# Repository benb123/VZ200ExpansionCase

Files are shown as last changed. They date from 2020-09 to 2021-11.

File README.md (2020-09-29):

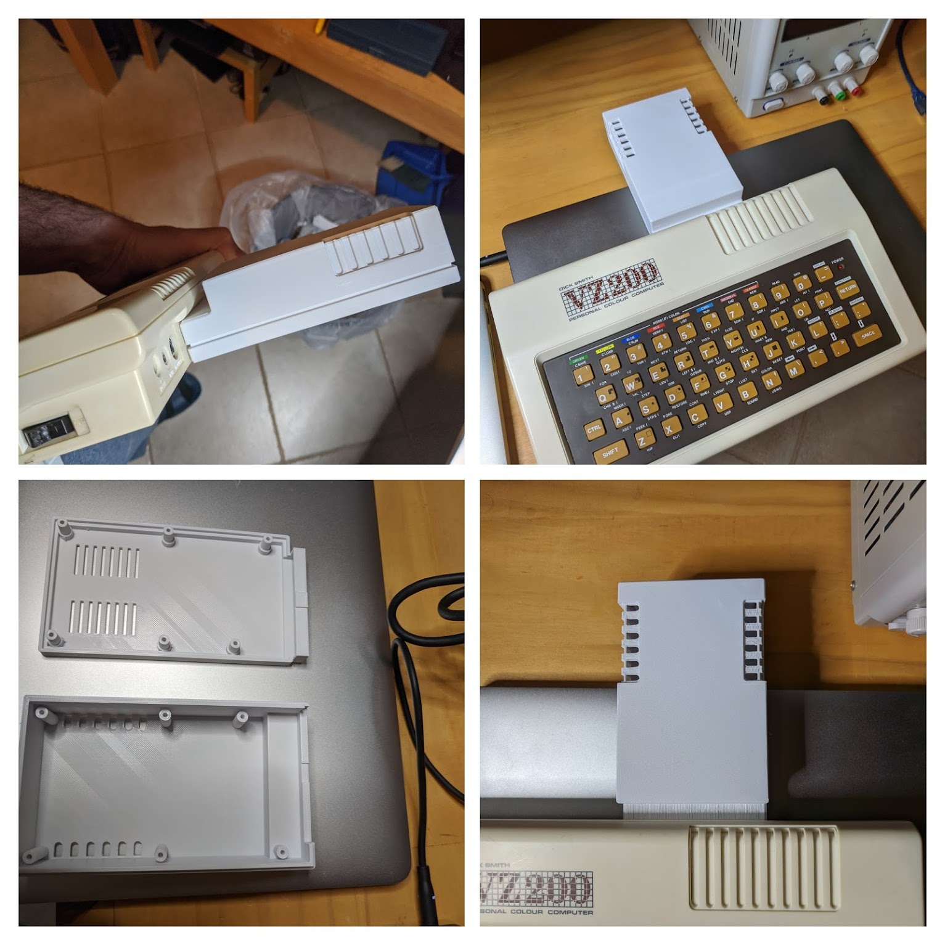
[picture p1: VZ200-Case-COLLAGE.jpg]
VZ200/300 Expansion Case


# What is this?

An Expansion case for the VZ200 with FreeCAD and STL files for 3D printing.

The original dimension have been used as best able to determine so that this case is suitable for recreating existing available hardware. The 3D model has been printed and fits the VZ200 expansion port OK.

Looking at the measurements, an 44x2 pin edge connector (last seen here https://www.ebay.com.au/itm/5pc-Industrial-Card-Edge-Slot-Socket-Connector-22x2P-44P-2-54mm-0-1-Right-Angle/133446391140) will fit.

# The Relevant Files

|File|Description|
|----|---|
|Base.stl|The bottom part of the case to 3D print.|
|TopCover.stl|The top part of the case to 3D print.|
|TopAndBase.stl|Both top and bottom parts for 3D printing in one session.|
|Expansion.FCStd|The FreeCAD file for editing the original model and exporting STL.|

# Credits

Replica FreeCAD Model Author: Ben Beazley

Thanks to David Maunder for providing the dimensions for this work. :-)

## Project Status

Waiting on any refinements to match better the original design (feedback).

# Contact the Author

Please find me (Ben Beazley) and other like-minded enthusiasts in the "VZ200 VZ300 Laser210 Laser310 fans" Facebook group. :-)

# License

This case is free for private use but not for sale *without the author's consent*.

If you would like to include this case as part of your profitable and non-trivial hardware project, that is an acceptable use case for this license. Simply selling an empty case is not.

# Change History

|Date|Author|Version|Change|
|----|---|---|---|
|29/Sep/2002|Ben Beazley|1.1|Revised to match the Original VZ Top Grill pattern. There was a missing raised portion on the top-most part of grill. Note the four tiled pictures in this Readme don't reflect this change at this time!|
|24/Sep/2002|Ben Beazley|1.0|First practical version that fitted the rear of the VZ200!|

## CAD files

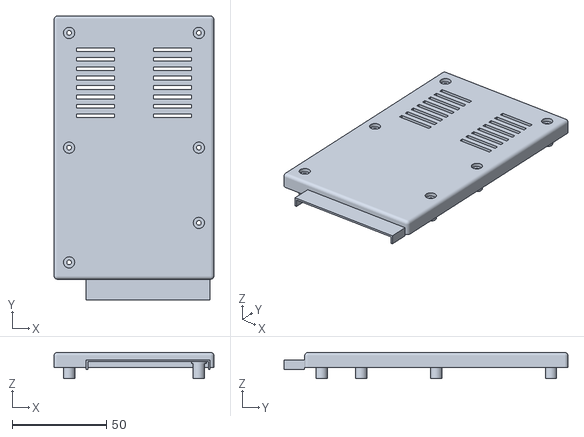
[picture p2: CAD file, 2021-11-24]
Base.stl
85.0 x 151.0 x 14.0

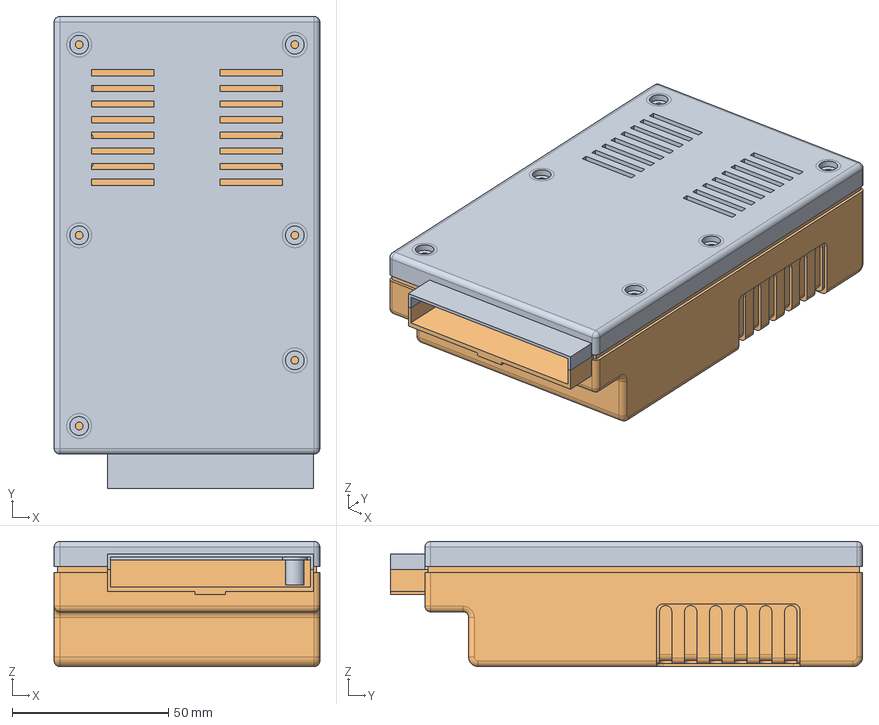
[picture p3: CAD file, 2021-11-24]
Expansion.FCStd
85.0 x 151.0 x 40.0 mm
BottomCaseRounding
TopCaseRounding

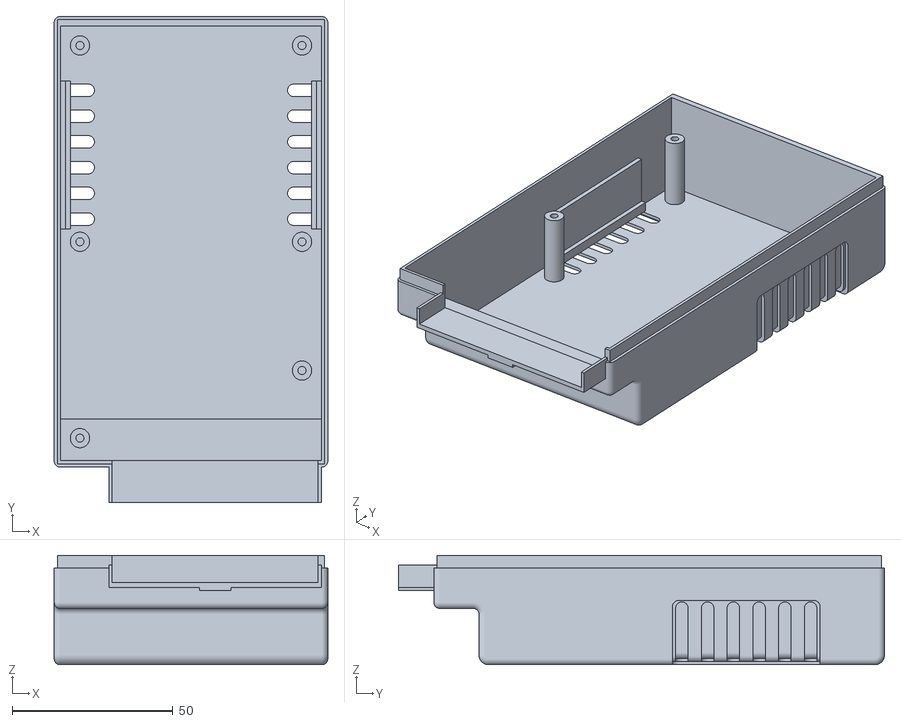
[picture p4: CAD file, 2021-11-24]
TopCover.stl
85.0 x 151.0 x 34.0

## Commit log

2020-09-19 Bottom Case. Needs feet still to raise a few mm. Also not filleted as yet.
    [Expansion.FCStd]
2020-09-20 Updated Readme to reflect current status. Not ready for use!
2020-09-20 Added air holes to base.
    [Expansion.FCStd]
2020-09-20 Base top case done. Needs grill design, filleting.
    [Expansion.FCStd]
2020-09-20 Begun top grills.
    [Expansion.FCStd]
2020-09-20 Redid last change to round the grills from top, left and right separately.
    [Expansion.FCStd]
2020-09-20 Side patterned grills done. Now the top patterned grills.
    [Expansion.FCStd]
2020-09-20 Top grills done.
    [Expansion.FCStd]
2020-09-20 Added top case posts and extended internal flange to be 4mm so that 2mm is visible.
    [Expansion.FCStd]
2020-09-20 Fixed top case post issue at front on top of case! Just reordered the pocketing to get the chunk out of the front at the end instead.
    [Expansion.FCStd]
2020-09-20 Added screw holes to top case mount.
    [Expansion.FCStd]
2020-09-20 A little refactoring of order.
    [Expansion.FCStd]
2020-09-20 Ready for edge connector part at front of case! Filleted all edges.
    [Expansion.FCStd]
2020-09-21 Added edge connector shroud to base. Need to cookie cut the top to match.
    [Expansion.FCStd]
2020-09-21 Edge connector top case cookie cut. Need to add filleting to top and bottom again.
    [Expansion.FCStd]
2020-09-22 "Complete" pending testing of actual dimensions in a real VZ200. Added STL exports for top and bottom!
    [Base.stl, Expansion.FCStd, TopCover.stl]
2020-09-23 Re-exported base.stl as it was missing filleting to round edges.
    [Base.stl]
2020-09-23 Added more curve to the edges (as much as I can without breaking the model).
    [Base.stl, Expansion.FCStd, TopCover.stl]
2020-09-23 Added all in one STL ready to print though feel free to adjust orientation for better surfaces.
    [TopAndBase.stl]
2020-09-24 Correction to fit back of VZ200. Removed 3mm from the "step".
    [Expansion.FCStd, TopAndBase.stl, TopCover.stl]
2020-09-29 Corrected top Grill to match VZ design. Extended Readme.md with change history, license tweak and file descriptions.
    [Expansion.FCStd, TopAndBase.stl, TopCover.stl]
2021-03-16 Split the edge connector shroud into two for the top and bottom.
    [Base.stl, Expansion.FCStd, TopCover.stl]
2021-03-16 Removed useless STL file.
    [TopAndBase.stl]
2021-11-24 Using an actual 16KB RAM Expansion module, I made the inside mounts align properly, and generally made the dimensions more accurate. The grills on the side are still the VZ sized grills and not the o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
    [Base.stl, Expansion.FCStd, TopCover.stl]
2021-11-24 Raised edge connector housing by 2mm on Base as it wouldn't fit in the VZ!
    [Base.stl, Expansion.FCStd]
2021-11-24 Updated Base.stl for last change.
    [Base.stl]
